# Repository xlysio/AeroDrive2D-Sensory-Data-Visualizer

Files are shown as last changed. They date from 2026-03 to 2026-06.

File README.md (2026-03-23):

# AeroDrive2D-Sensory-Data-Visualizer
AeroDrive2D is an interactive 2D racing game driven by a custom-built, gesture-based physical controller. This project bridges hardware sensor integration with real-time software rendering and data telemetry.

🎮 How It Works

The system discards traditional gamepads in favor of a custom spherical controller resting on a desk, operated with both hands:

    Steering (Left/Right): Achieved by physically tilting the controller. The tilt angle is calculated using the built-in IMU (Gyroscope/Accelerometer) of the Arduino Nano 33 IoT.

    Acceleration (Speed): Controlled contactlessly by the vertical distance of the desk from a VL53L0X Time-of-Flight (ToF) laser sensor. The closer the conotroller is to the desk, the faster the car goes.

The objective is simple: complete a 5-lap time trial as fast as possible.

⚙️ Key Technical Features
S
    Real-Time Telemetry: Live plotting of incoming sensor data (distance and tilt angle) using Qt Charts (strip chart format).

    Robust Serial Communication: Seamless data parsing from the microcontroller via a virtual COM port over USB (QSerialPort).

    Bilingual GUI: Fully internationalized user interface (English/Polish) implemented via Qt Linguist (QTranslator).

    Scalable Architecture: Responsive and geometry-independent layout built with Qt Layouts (QVBoxLayout, QHBoxLayout).

    Academic-Grade Documentation: Fully documented C++ source code generated using Doxygen.

🛠️ Tech Stack

    Hardware: Arduino Nano 33 IoT, VL53L0X (Pololu), Custom 3D-printed controller (Autodesk Fusion).

    Software: C++17, Qt Framework (QtWidgets, Qt Charts, Qt SerialPort), Arduino IDE, CMake.

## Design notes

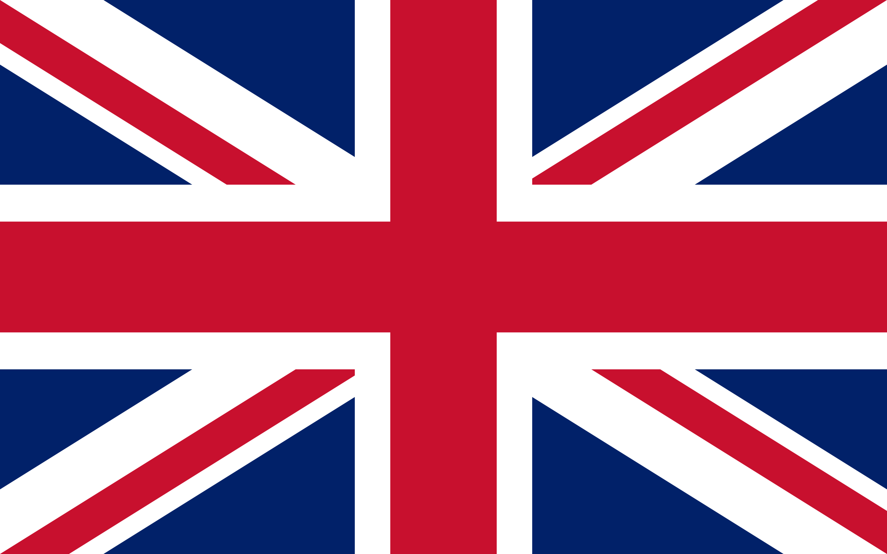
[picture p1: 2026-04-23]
software/pc_application/resources/flag_british.png

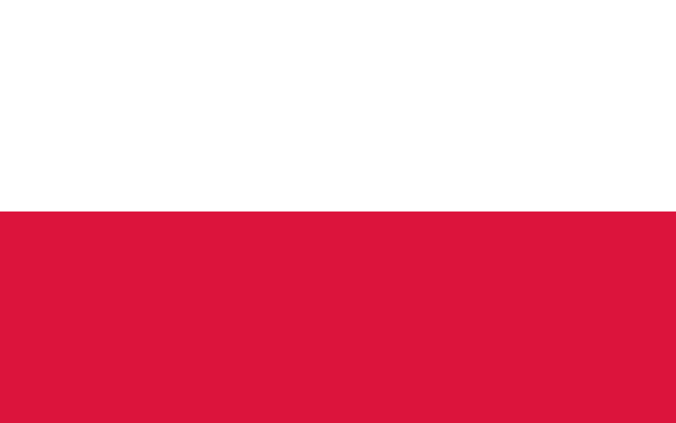
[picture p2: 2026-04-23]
software/pc_application/resources/flag_polish.png

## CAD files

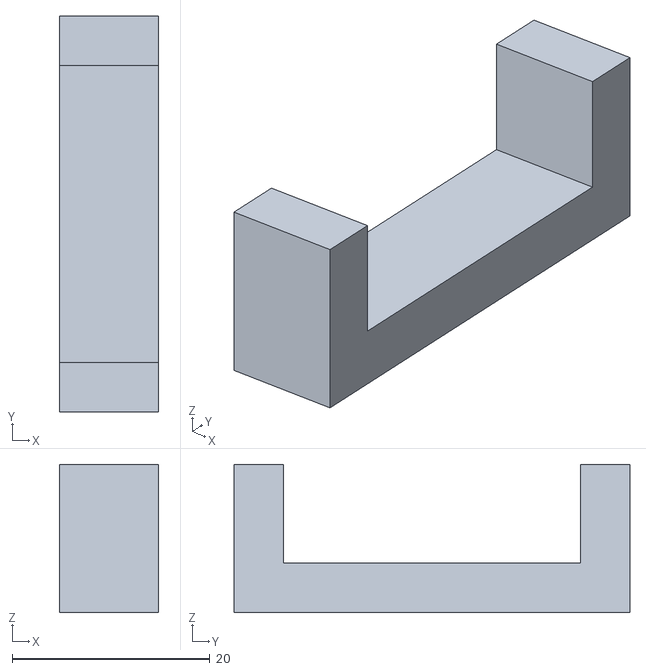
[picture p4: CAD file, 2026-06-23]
cad/bridge.stl
10.0 x 40.0 x 15.0

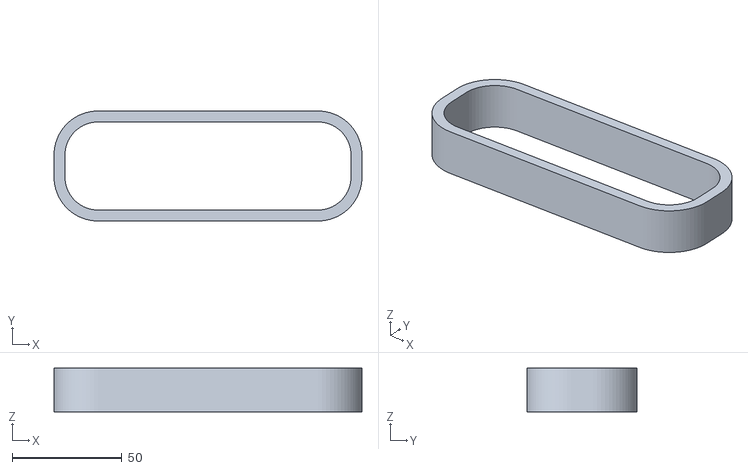
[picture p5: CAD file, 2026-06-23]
cad/base.stl
140.0 x 50.0 x 20.0

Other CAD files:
cad/base.f3d
cad/bridge.f3d
cad/controller.f3z

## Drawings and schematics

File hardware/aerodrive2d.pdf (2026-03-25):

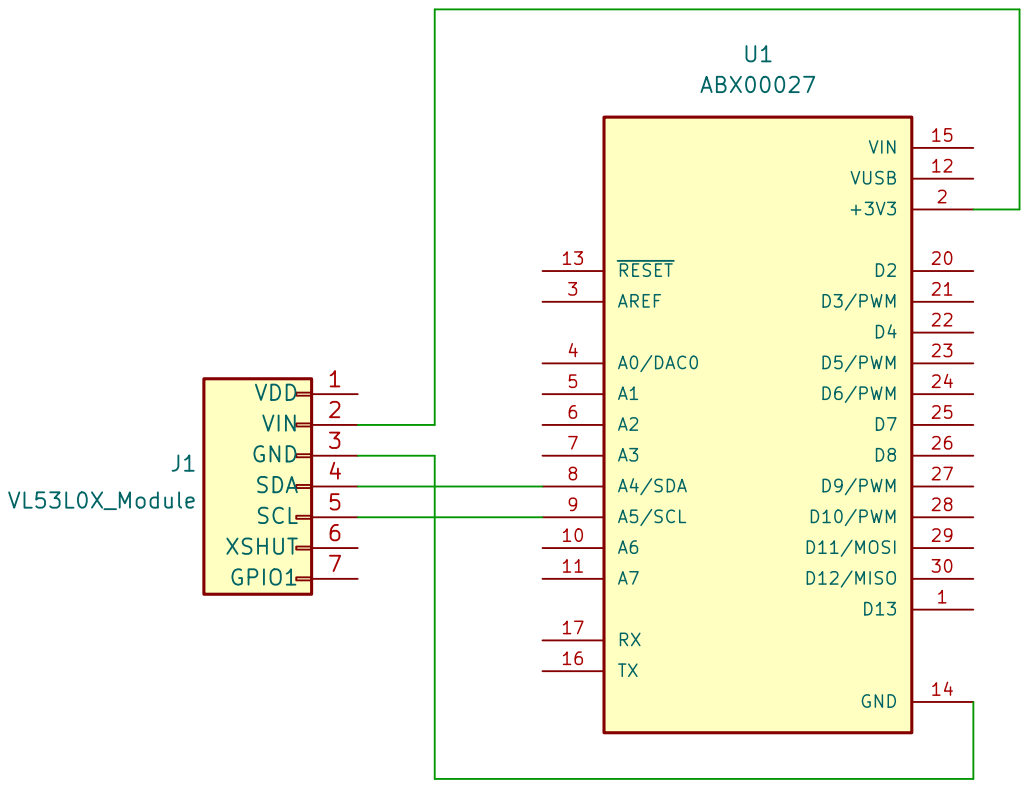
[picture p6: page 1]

Size: A4 | Rev:
KiCad E.D.A. 10.0.0 | Id: 1/1

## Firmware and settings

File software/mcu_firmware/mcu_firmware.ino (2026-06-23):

#include <Arduino_LSM6DS3.h>
#include "Adafruit_VL53L0X.h"
#include <math.h>
#include <avr/dtostrf.h>

// For NANO 33 IoT:
// - VIN to VIN (red)
// - GND to GND (black)
// - SDA to A4 (white)
// - SCL to A5 (brown)

// gyro - x axis
// left - minus
// right - plus

// acc - y and z axis
// left - minus
// right - plus

Adafruit_VL53L0X sensor = Adafruit_VL53L0X();
float acc_x, acc_y, acc_z, gyro_x, gyro_y, gyro_z, dt, acc_deg, acc_rad, gyro_deg, real_distance;
float angle_deg = 0.0;
float angle_rad = 0.0;
uint16_t measured_distance;
VL53L0X_RangingMeasurementData_t measure;
unsigned long current_time = 0;
unsigned long previous_time = 0;
const float alpha = 0.96;
char buf[10];
char frame[100];
int position;

void setup() 
{
  Serial.begin(115200);
  while (!Serial);

  if (!IMU.begin()) 
  {
    Serial.println("Failed to initialize IMU!");

    while (1);
  }

  if (!sensor.begin()) 
  {
    Serial.println("Failed to initialize ToF sensor!");
    while(1); 
  }
}

void loop()
{
  current_time = micros();

  // 50 Hz when dt = 20000
  // 1 Hz when dt = 1000000
  if (current_time - previous_time < 20000)
  {
    return;
  }

  dt = float((current_time - previous_time) / 1000000.0f);
  previous_time = current_time;

  if (IMU.accelerationAvailable() && IMU.gyroscopeAvailable())  
  {
    IMU.readAcceleration(acc_x, acc_y, acc_z);
    IMU.readGyroscope(gyro_x, gyro_y, gyro_z);

    acc_rad = atan2(acc_y, acc_z);
    acc_deg = acc_rad * 180.0 / M_PI;
    gyro_deg =  angle_deg + gyro_x * dt;

    angle_deg = alpha * gyro_deg + (1.0 - alpha) * acc_deg;
    angle_rad = angle_deg * M_PI / 180.0;
  }

  sensor.rangingTest(&measure, false);

  if (measure.RangeStatus != 4 && measure.RangeMilliMeter < 500) 
  {  
    measured_distance = measure.RangeMilliMeter;
    real_distance = float(measured_distance * cos(angle_rad));
  } 
  else 
  {
    measured_distance = 500.0;
    real_distance = 500.0;
  }
  
  position = 0;

  position += snprintf(frame + position, sizeof(frame) - position, "AD,%d,", measured_distance);
  dtostrf(real_distance, 1, 2, buf);
  position += snprintf(frame + position, sizeof(frame) - position, "%s,", buf);
  dtostrf(acc_deg, 1, 2, buf);
  position += snprintf(frame + position, sizeof(frame) - position, "%s,", buf);
  dtostrf(gyro_deg, 1, 2, buf);
  position += snprintf(frame + position, sizeof(frame) - position, "%s,", buf);
  dtostrf(angle_deg, 1, 2, buf);
  position += snprintf(frame + position, sizeof(frame) - position, "%s", buf);

  int checksum = 0;
  for (int i = 0; i < position; ++i)
  {
    checksum ^= frame[i];
  }

  Serial.print("$");
  Serial.print(frame);
  Serial.print("*");
  if (checksum < 0x10)
  {
    Serial.print("0");
  }
  Serial.println(checksum, HEX);
}

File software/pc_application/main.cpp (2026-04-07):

/**
 * @file main.cpp
 * @brief Creates the QApplication instance and displays the main window.
 */

#include "mainwindow.h"

#include <QApplication>

/**
 *  @brief Application's main function
 * @param argc Number of arguments.
 * @param argv Array of type string arguments.
 * @return Exit code returned by Qt.
 */
int main(int argc, char *argv[])
{
    QApplication a(argc, argv);
    MainWindow w;
    w.show();
    return QCoreApplication::exec();
}

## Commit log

2026-03-25 added a electronics schematic made in KiCad
    [aerodrive2d.kicad_pcb, aerodrive2d.kicad_sch]
2026-04-06 changed titles for y axises of both charts
2026-04-19 added gamewidgetclass and race circuit
2026-04-20 added game logic to GameWidget and connected it to MainWindow - early stage of working game
2026-04-22 added connect button to establish or end connection with serial port
2026-04-23 added icon flags to language buttons
2026-04-23 resized start/restart button to match other ones
2026-04-24 updated frame documentation in serial handler header
2026-06-09 switched lap times to yellow
2026-06-10 doxygen file include sources parameter switched to yes
2026-06-23 controller design and stl files
    [base.f3d, base.stl, bridge.f3d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]
